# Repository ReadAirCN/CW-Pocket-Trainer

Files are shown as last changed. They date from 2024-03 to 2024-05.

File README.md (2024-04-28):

# 便携CW训练器 CW-Pocker-Trainer

## 仓库简介
  - **3D-Models**: 包含可编辑和打印的STEP模型文件。PLA文件夹内的模型建议使用PLA或其他刚性耗材打印，TPU文件夹内的模型建议使用TPU 95A或其他柔性耗材打印。
  - **Firmware**: 包含可以直接下载的固件，所有固件均可使用WCHISPTool下载， WCHISPTool的安装包也在此文件夹中，CH549G-WCHLINK-Firmware是调试芯片的固件，只需在第一次烧录即可（对于从工房买到焊好的PCB板,此固件已经烧录完成），CH32F103C8T6-Main-Firmware是主控芯片的固件，下载不同固件可以实现不同的功能，每个固件具体的介绍在该文件夹中。
  - **Keil-Project**: CW训练器的源码工程,Keil中设置调试器为CMSIS-DAP Debugger可直接编译下载到训练器。
  - 具体介绍参考项目中的 “便携CW训练器使用说明.pdf”

本项目完全开源，欢迎贡献代码。
## 交流群
QQ交流群：798617844   进群答案为：**ReadAir**



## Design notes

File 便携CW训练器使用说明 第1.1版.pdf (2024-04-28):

# 便携 CW 训练器使用说明

V1.1
BD4XUW

目录

## 1 训练器介绍

### 1.1 功能简介

便携 CW 训练器用于 QRP 爱好者在不发射的情况下进行莫斯电码的自我训练，目前支持的模式有自由 模式、训练模式、默写模式和听译模式。训练器留有一个 TypeC 接口和一个 3.5mm 音频接口，TypeC 接口 可用于串口通讯、更新固件、为训练器供电或充电（充电电流不超过 600mA）。3.5mm 音频接口可以接入耳 机，将声音输出至耳机从而在不方便外放的场合使用。

### 1.2 参数简介

⚫ | 外观尺寸：训练器主体 80*40*30mm,自动键状态 112*40*30mm;
⚫ | 电池：3.7V 800mAh 锂电池;
⚫ | 充电电流：≤600mA;
⚫ | 材质：PLA\TPU

### 1.3 拓展功能

⚫ | 更新固件
⚫ | 串口调试
⚫ | 二次开发
⚫ | 手键模式（即将添加）

## 2 使用方法

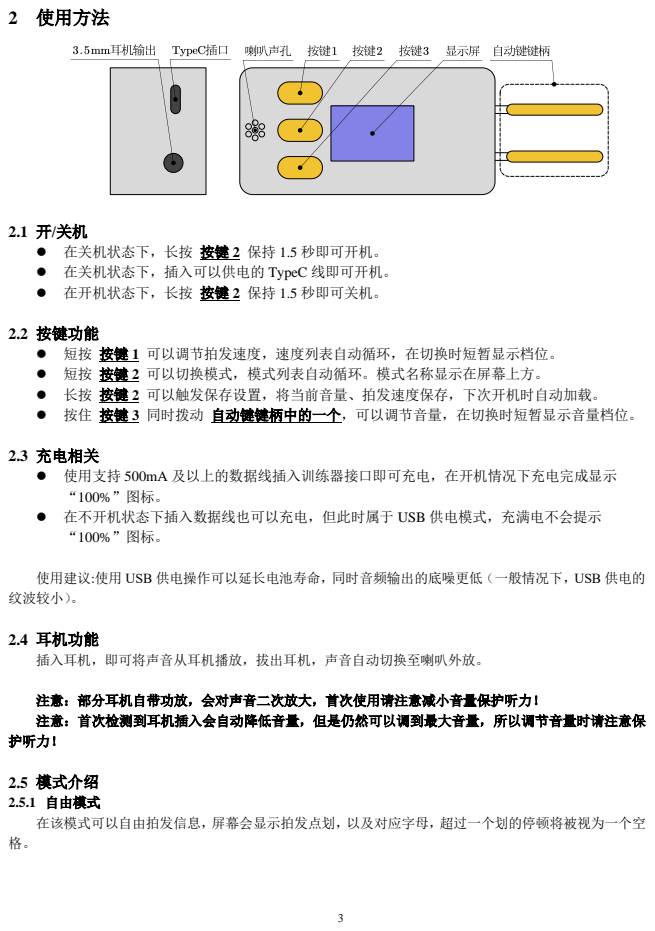
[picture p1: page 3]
在关机状态下，长按 按键 2 保持 1.5 秒即可开机。; 在关机状态下，插入可以供电的 TypeC 线即可开机。; 在开机状态下，长按 按键 2 保持 1.5 秒即可关机。; 2.2 按键功能; 短按 按键 1 可以调节拍发速度，速度列表自动循环，在切换时短暂显示档位。; 短按 按键 2 可以切换模式，模式列表自动循环。模式名称显示在屏幕上方。; 长按 按键 2 可以触发保存设置，将当前音量、拍发速度保存，下次开机时自动加载。; 按住 按键 3 同时拨动 自动键键柄中的一个，可以调节音量，在切换时短暂显示音量档位。; 2.3 充电相关; 使用支持 500mA 及以上的数据线插入训练器接口即可充电，在开机情况下充电完成显示; 在不开机状态下插入数据线也可以充电，但此时属于 USB 供电模式，充满电不会提示

使用建议:使用 USB 供电操作可以延长电池寿命，同时音频输出的底噪更低（一般情况下，USB 供电的
纹波较小）。

2.4 耳机功能
插入耳机，即可将声音从耳机播放，拔出耳机，声音自动切换至喇叭外放。

注意：部分耳机自带功放，会对声音二次放大，首次使用请注意减小音量保护听力！
注意：首次检测到耳机插入会自动降低音量，但是仍然可以调到最大音量，所以调节音量时请注意保
护听力！

2.5 模式介绍
2.5.1 自由模式
在该模式可以自由拍发信息，屏幕会显示拍发点划，以及对应字母，超过一个划的停顿将被视为一个空

2.5.2练习模式
在该模式屏幕会同时显示字母与对应点划，正确或错误拍发会播放对应提示音。准确率会显示在屏幕下 方。

2.5.3默写模式
在该模式屏幕只显示字母，操作者需要正确拍发该字母对应点划，正确或错误拍发会播放对应提示音。 准确率会显示在屏幕下方。

2.5.4听译模式
在该模式中，训练器会先播放一个字母的莫斯电码音，播放完成一次后，屏幕会会显示码元长度相等的 两个字母备选项，其中一个为正确答案，操作者拨动桨片选择正确答案。正确或错误拍发会播放对应提示 音。准确率会显示在屏幕下方。如果第一遍播放未听清，1.5 秒后会重复播放直到操作者做出选择。

### 2.6 固件更新

训练器支持更新固件和二次开发（板载调试器，支持实时调试），对于一般使用者，只需在必要时更新 固件即可。固件可在 QQ 群或 Github 工程（暂未公开）中找到。
以下是常规固件更新流程
1.在关机状态下先同时捏住双桨，此时插入带数据功能的 TypeC 线(线的一端已连接到电脑并供电)。此 时如成功，屏幕应该无显示。

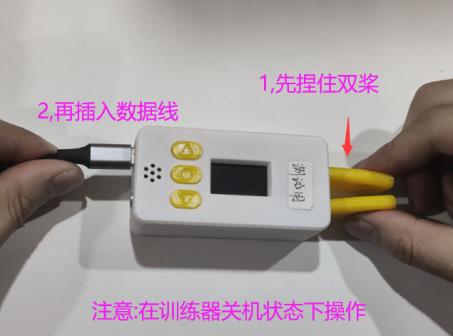
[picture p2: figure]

2.打开软件 WCHISPTOOL，选择对应 COM 口，将要下载的固件（BIN 或者 HEX 格式）放到目标程 序文件 1，确保其他选项与下图一致。

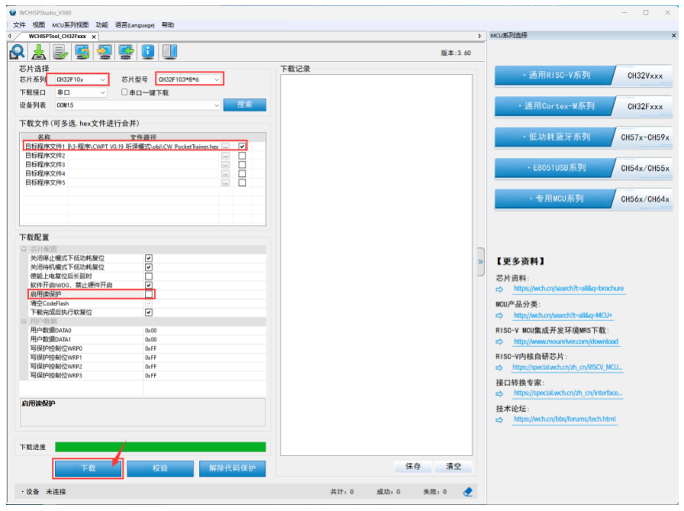
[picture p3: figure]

3.点击下载后若成功则如下图所示：

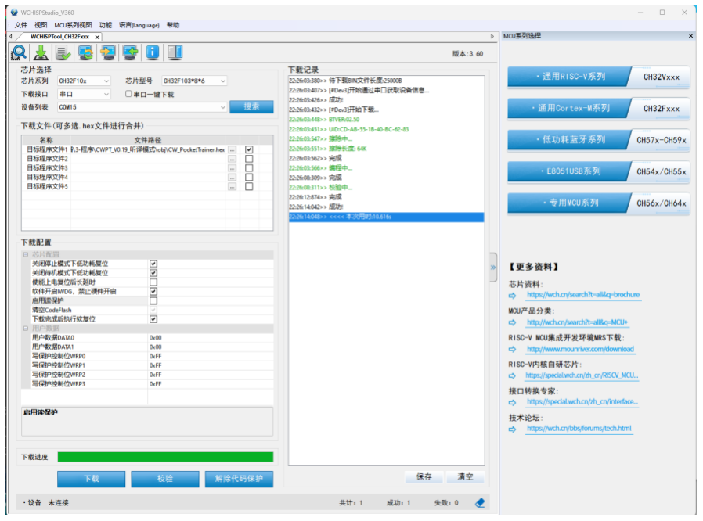
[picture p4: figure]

4.拔除数据线重新开机即可，此时已经下载好新固件了。

## 3 如何拆解

### 3.1 拆解步骤

（1）打开外壳
对于原装的训练器，如果没有粘壳，抓住键柄那一端的两侧即可打开外壳，如果粘壳了，需要 用工具（如小刀，一字螺丝刀）撬开图 1 位置，这种方法会对外壳造成破坏，不过外壳可以在 群文件或 Github 项目中下载 3D 模型自行打印。
（2）取出电池
电池使用易剥离双面胶固定，用一字螺丝刀从电池远离电路板的方向轻轻发力即可取出。 （3）取出电路板
电路板从图 3 所示缺口撬开，注意撬开后不要暴力拖拽，小心图 4 所示的喇叭线被扯断 （4）取出喇叭
喇叭使用背胶粘在外壳上，建议用镊子或其他工具小心取下，不要拉扯喇叭线以免扯断。

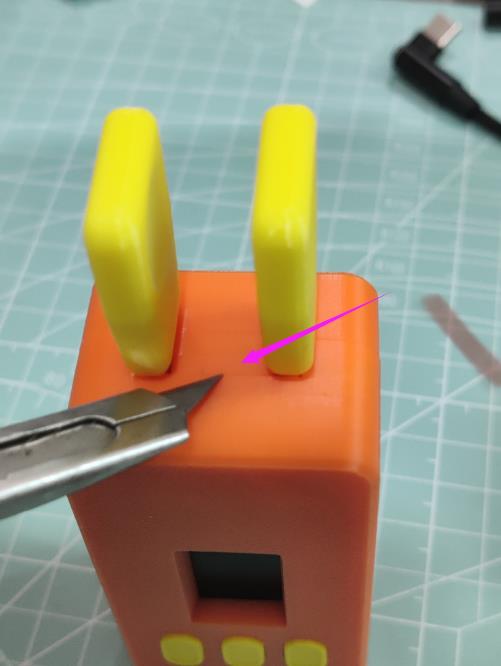
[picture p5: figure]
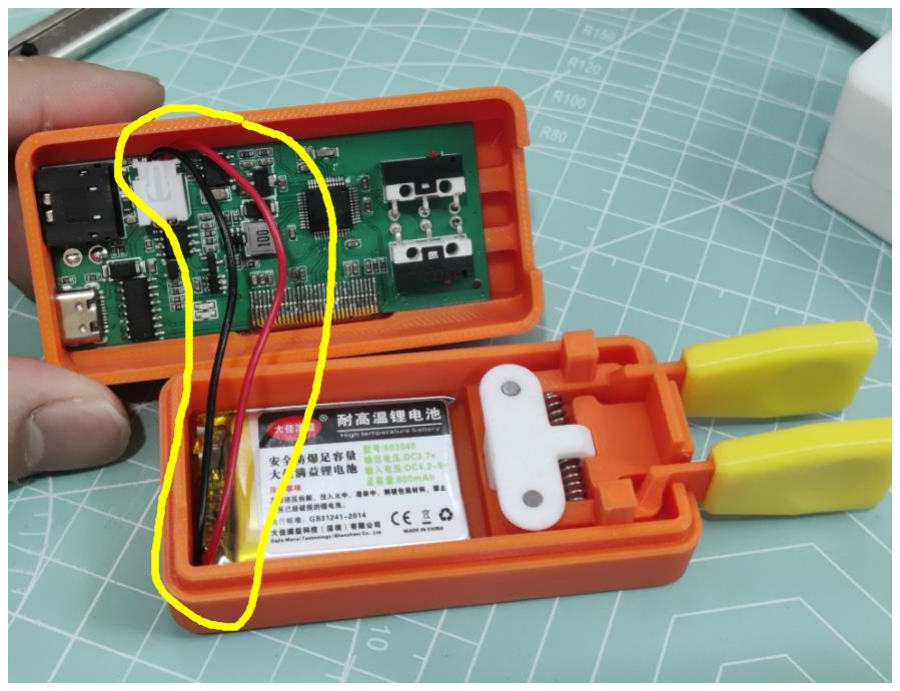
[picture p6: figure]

图 1 粘壳训练器从此处撬开 | 图 2 撬开之后小心电池线

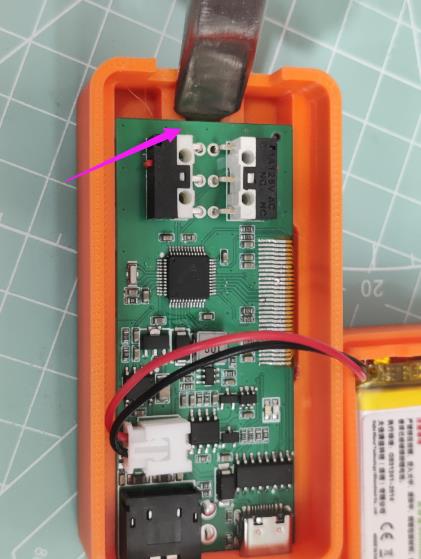
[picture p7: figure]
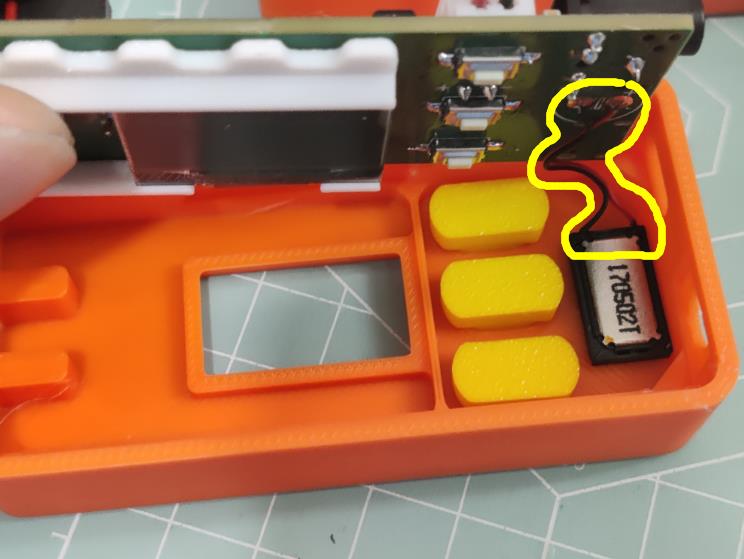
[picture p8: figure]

图 3 从图示位置可撬开电路板 | 图 4 撬开之后小心喇叭线

### 3.2 易损零件参数

名称 | 参数
锂电池 | 3.7V 聚合物锂电池 603040 800 毫安时
喇叭 | 2W 通用扬声器 16*9*2.5mm 11 号
圆柱销 | 304 不锈钢圆柱销 φ3*10
弹簧 | 304 不锈钢压簧 0.5*4*25
垫圈 | 尼龙垫圈/绝缘套管 φ3*7*5

## 4 其他

### 4.1 QQ 群

进群答案是 ReadAir

### 4.2 Bilibili 主页

https://space.bilibili.com/6397781

### 4.3 Github

正在整理代码，即将公开。

### 4.4 关于开源

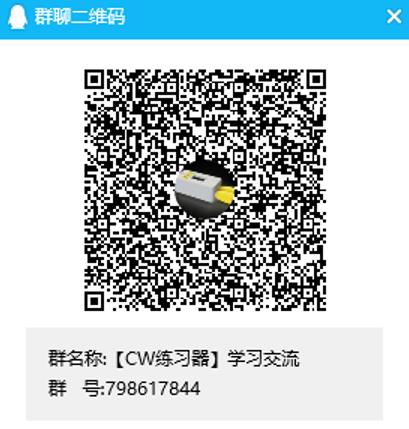
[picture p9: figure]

综合考虑后，决定开源除 PCB 生产文件之外的所有资料，开源内容包括
⚫ | 外壳三维设计文件
⚫ | 各版本固件
⚫ | 稳定版 Keil 工程
⚫ | PCB 原理图
部分内容在 Q 群中已经可以获得，

本作者对该项目的态度是：
欢迎复刻，欢迎爆改，欢迎二次创作。对于二次创作的作品，如果想售卖也没有问题，不要使用我的名 义即可。希望大家都能借助这个项目学到自己感兴趣的知识，激发大家对业余无线电以及 QRP 的兴趣。

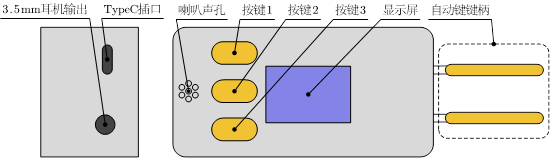
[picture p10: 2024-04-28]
image.png

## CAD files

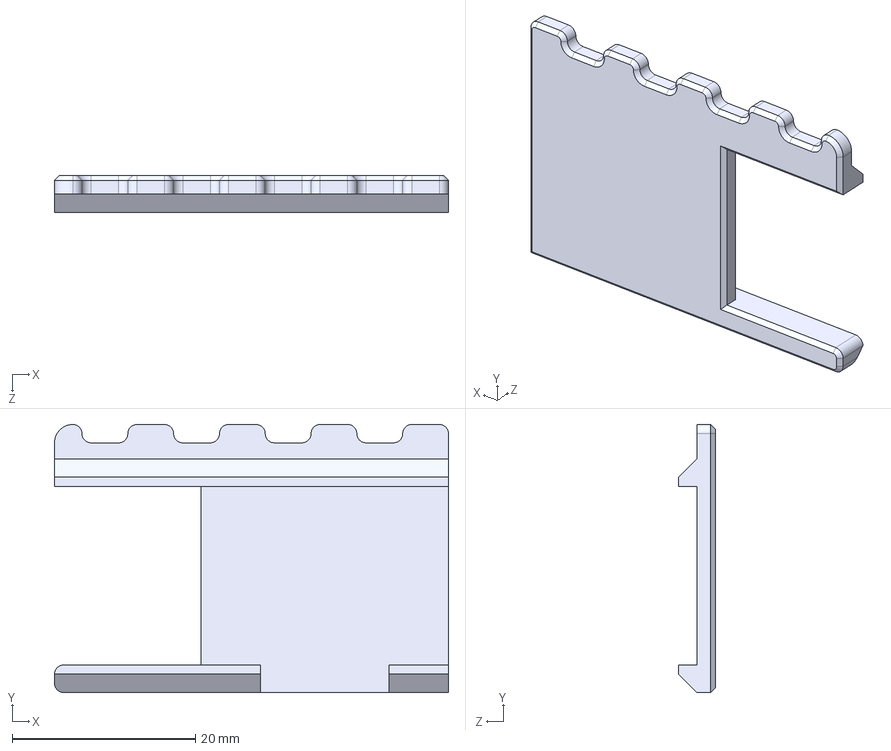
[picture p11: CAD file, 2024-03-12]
3D-Models/PLA-Material/OLED固定架.STEP
43.0 x 29.2 x 4.00 mm

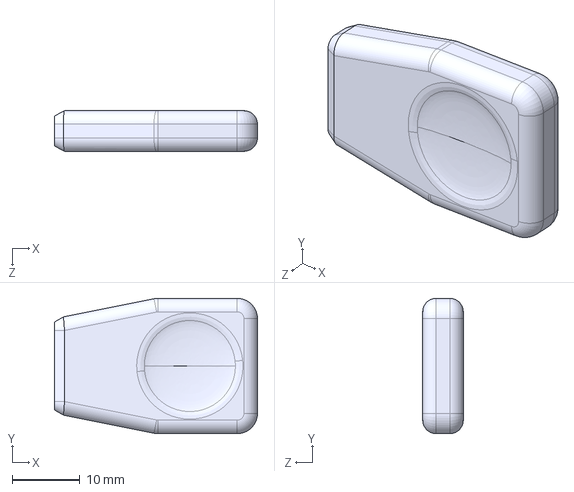
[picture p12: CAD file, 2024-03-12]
3D-Models/TPU-Material/自动键键帽.STEP
30.0 x 20.0 x 6.00 mm

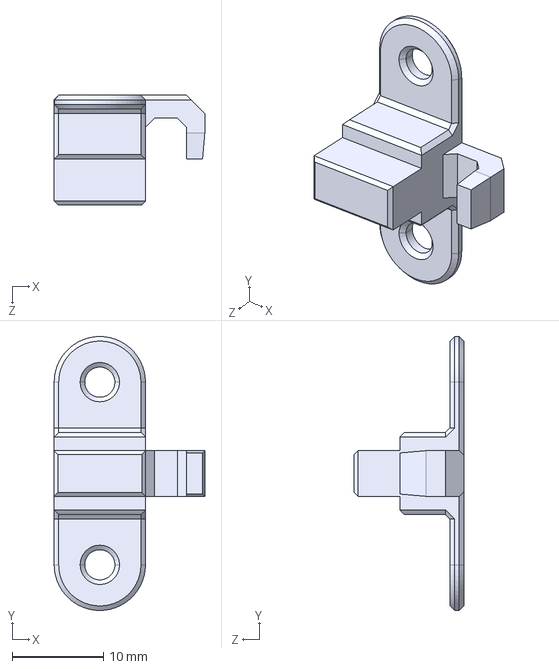
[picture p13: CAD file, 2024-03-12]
3D-Models/PLA-Material/自动键固定器.STEP
16.5 x 30.0 x 12.0 mm

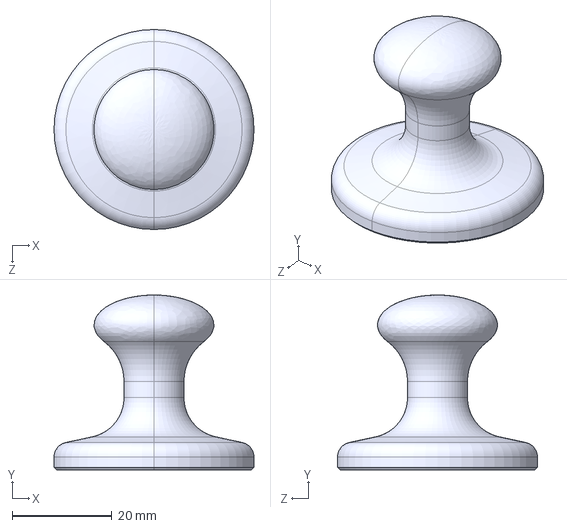
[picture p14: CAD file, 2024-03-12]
3D-Models/TPU-Material/手键键帽.STEP
40.0 x 35.0 x 40.0 mm

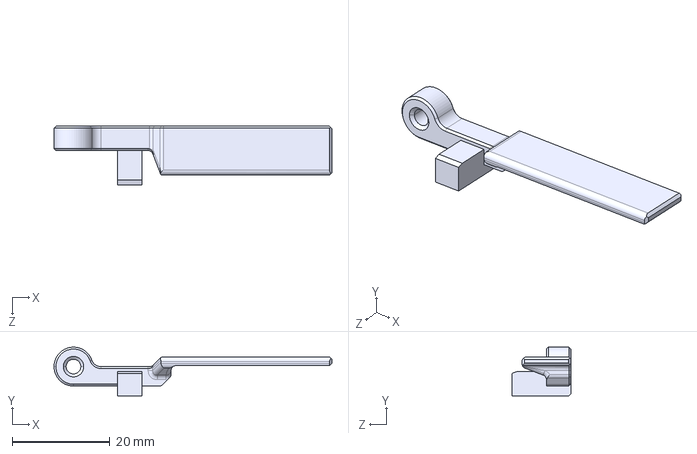
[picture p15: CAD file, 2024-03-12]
3D-Models/PLA-Material/新自动键键柄左.STEP
57.0 x 10.00 x 12.0 mm

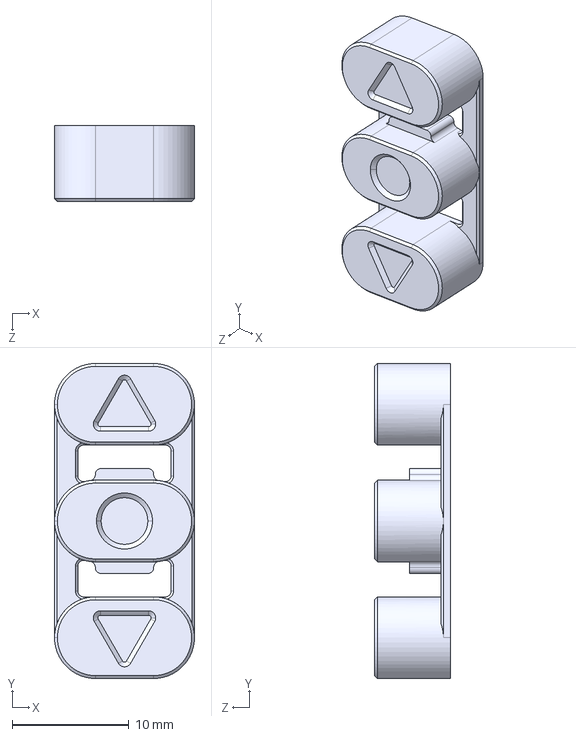
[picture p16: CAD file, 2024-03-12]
3D-Models/TPU-Material/TPU按键.STEP
12.0 x 27.0 x 6.50 mm

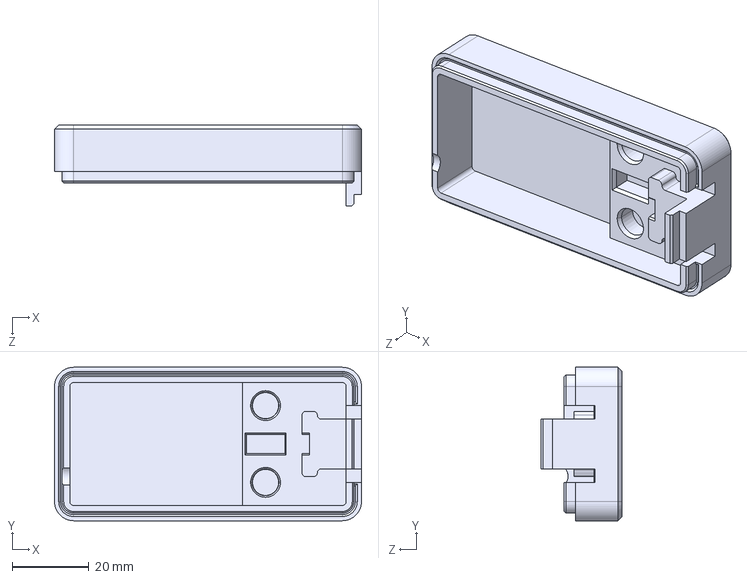
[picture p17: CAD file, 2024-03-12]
3D-Models/PLA-Material/CWPT下壳_导流槽.STEP
80.0 x 40.0 x 21.0 mm

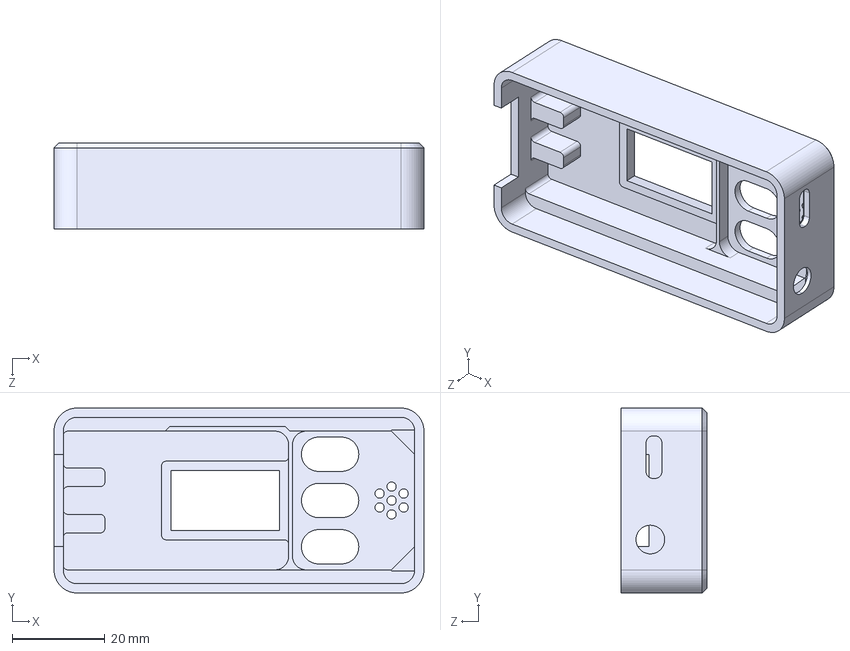
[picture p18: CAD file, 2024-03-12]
3D-Models/PLA-Material/CWPT上壳_安装导向.STEP
80.0 x 40.0 x 18.5 mm

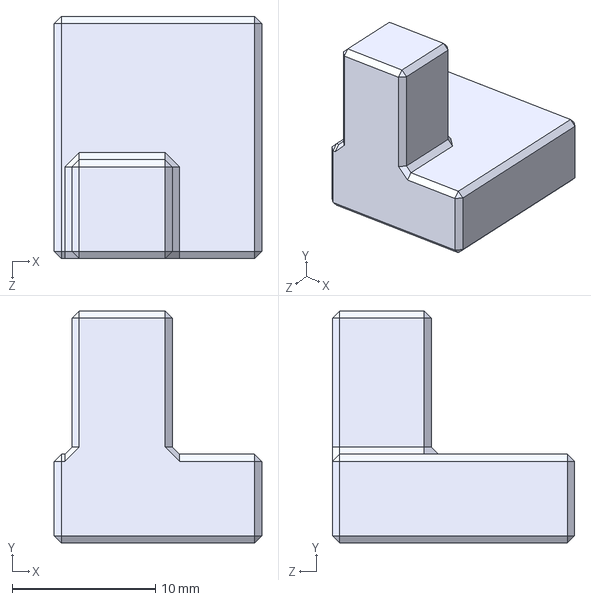
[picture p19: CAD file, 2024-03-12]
3D-Models/PLA-Material/手动键转接板.STEP
14.5 x 16.2 x 16.9 mm

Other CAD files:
3D-Models/PLA-Material/新自动键键柄右.STEP

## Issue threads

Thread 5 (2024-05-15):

关于发送队列

violarulan, 2024-05-15:
在实机操作中，使用双桨自动键可以做到发送“队列”的操作，如快速拍击“左右左”，即使手上的动作已结束，机器仍然可以输出三个交替嘀嗒。

不知可否集成这个 feature

相关链接 [S8050做的CW电路也能到2W](https://www.hellocq.net/forum/read.php?tid=170016&page=2)

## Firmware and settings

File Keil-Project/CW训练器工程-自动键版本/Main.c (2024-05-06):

#include "debug.h"
// 显示屏驱动
#include "oled.h" 
// ADC驱动，包括电池电压和耳机插入检测
#include "BSP_adc.h"
// 按键和自动键初始化
#include "Key.h"
// 电池与TP4056初始化
#include "battery.h"
// 喇叭功放驱动
#include "beep.h"
// 定时器驱动，包括主程序逻辑
#include "timer.h"
// FLASH保存
#include "flash.h"
// DAC驱动，包括喇叭发生驱动
#include "dac.h"
// OLED用户交互函数
#include "oled_ui.h"
// 莫斯电码相关
#include "cw.h"
// 标准库函数
#include <stdlib.h>



// 音量幅值列表
const float VolumeList[9]={0.0003,0.001,0.003,0.1,0.2,0.4,0.6,0.8,1};
// 音量改动标志位
u8 VolumeChange_Flag = 0;
// 音量修改标志位
u8 VolumeModified_Flag = 1;
// 耳机模式标志位
u8 EarPhone_MODE_FLAG = 0;
void HardWare_Init(void)
{
		// 延迟函数初始化
		Delay_Init();
		// 设置系统中断优先级分组
		NVIC_PriorityGroupConfig(NVIC_PriorityGroup_2); 
		/* 串口调试初始化（发行版暂时不需要）*/
		/* USART_Printf_Init(115200); */ 
		// OLED初始化
		OLED_Init();
		// 电池电压ADC初始化
		BSP_ADC_Init();
		// 按键初始化
		Button_Init();
		// 电键初始化
		DKEY_Init();
		// 充电芯片状态识别初始化
		Battery_TP4056_GPIO_Init();
		// 功放静音输出初始化
		AmpSD_GPIO_Init();
		// 创建MorseTree
		MorseTree_Init();
		// 定时器初始化(1000Hz)
		TIM1_TASK_Init(1000-1,72-1);
		delay_ms(10);
		// Flash读写初始化
		
		// DAC初始化
		DAC_MUSIC_Init();
		// 正弦波波以及调整音量
		EarPhone_WAVE(WAV_DATA3,VolumeList[VolumeList_index]);
		VolumeModified_Flag = 1;
		// 初始化随机数生成器
    srand((unsigned int)Battery_Voltage+TIM1->CNT);
}


int main( void )
{
	u8 key_value=0;
	
	//初始化
	HardWare_Init();

	OLED_Refresh_Gram();
	BSP_Flash_Read_Info();
	
	{/*更新时间设定*/
	switch(GLOBAL_SendSpeed)
	{
		case SendSpeed_Slow:
		{
			time_dit = TIME_SLOW_dit;
			break;     
		}              
		case SendSpeed_Middle:
		{
			time_dit = TIME_MIDD_dit;
			break;
		}	
		case SendSpeed_High:
		{
			time_dit = TIME_HIGH_dit;
			break;
		}
		case SendSpeed_Super:
		{
			time_dit = TIME_SUPR_dit;
			break;
		}	
	}
	time_dah = 3 * time_dit;
	time_space_bit = time_dit;
	time_space_letter = 3 * time_dit;
	time_space_word = 7 * time_dit;
	}/*更新时间设定*/
	
//BSP_Flash_Write_Info();
	
	{ // 修复开机爆破音
		EarPhone_WAVE(WAV_DATA3,VolumeList[VolumeList_index]);
		DAC_SetFreq(1000);
		TIM_Cmd(TIM3, ENABLE);
		AMP_SD = 0;
	} // 修复开机爆破音
	while(1)
	{
		// 按键检测
		key_value = Button_Scan();
		// 强制打乱，可能没有意义
		srand((unsigned int)Battery_Voltage+TIM1->CNT);
		
		if (key_value == BUTTON_DEC_PRES)//切换拍发速度
		{
			switch(GLOBAL_SendSpeed)
			{
				case SendSpeed_Slow:
				{
					GLOBAL_SendSpeed = SendSpeed_Middle;
					time_dit = TIME_MIDD_dit;
					break;     
				}              
				case SendSpeed_Middle:
				{
					GLOBAL_SendSpeed = SendSpeed_High;
					time_dit = TIME_HIGH_dit;
					break;
				}	
				case SendSpeed_High:
				{
					GLOBAL_SendSpeed = SendSpeed_Super;
					time_dit = TIME_SUPR_dit;
					break;
				}
				case SendSpeed_Super:
				{
					GLOBAL_SendSpeed = SendSpeed_Slow;
					time_dit = TIME_SLOW_dit;
					break;
				}	
			}	
			// 更新时间设定
			time_dah = 3 * time_dit;
			time_space_bit = time_dit;
			time_space_letter = 3 * time_dit;
			time_space_word = 7 * time_dit;
			UI_SendSpeedDisplay(GLOBAL_SendSpeed);
			OLED_Refresh_Gram();
			delay_ms(500);
		}
		else if (key_value == BUTTON_MODE_PRES) // 切换模式（自由练习，看字直发，看字盲发，听译模式）
		{
			OLED_Clear();
			// 目的是防止上一个模式中的音乐没有放完
			TIM_Cmd(TIM3, DISABLE);
			// 目的是确保进入新模式的时候新生成一个字母
			GLOBAL_FLAG_NewLetter = 1;
			// 设置初始准确率，只是为了好看
			GLOBAL_ratio_correct = 100.0;
			switch(GLOBAL_WorkMode)
			{
				case WorkMode_FreeType:
				{
					GLOBAL_WorkMode = WorkMode_RandType;
					break;     
				}              
				case WorkMode_RandType:
				{
					GLOBAL_WorkMode = WorkMode_BlindType;
					break;
				}	
				case WorkMode_BlindType:
				{
					GLOBAL_WorkMode = WorkMode_ListenType;
					break;
				}	
				case WorkMode_ListenType:
				{
					GLOBAL_WorkMode = WorkMode_FreeType;
					strcpy(GLOBAL_BottomString,"                ");
					ClearStr(CW_Code,7);
					CW_Letter='\0';
					break;
				}	
			}	
		}
		// 按住第三按键
		if (BUTTON_INC == 0)
		{
			// 编辑音量时不响应CW逻辑
			GLOBAL_FLAG_WORKING = 0;
			
			if ((DKEY_A == 1) && (DKEY_B == 1))//松开视为已经修改
			{
				VolumeChange_Flag = 0;
				if (VolumeModified_Flag == 0)
				{
					// 调整音量
					EarPhone_WAVE(WAV_DATA3,VolumeList[VolumeList_index]);
					VolumeModified_Flag = 1;
					UI_VolumeDisplay(VolumeList_index);
					OLED_Refresh_Gram();
					TIM_Cmd(TIM3, ENABLE);
					delay_ms(300);
					TIM_Cmd(TIM3, DISABLE);
				}
			}
			if (VolumeChange_Flag == 0)
			{
				if (DKEY_A == 0)//音量+
				{
					VolumeList_index = (VolumeList_index >= 8)?8:VolumeList_index +1;
					VolumeChange_Flag = 1;
					VolumeModified_Flag = 0;
				}
				else	if (DKEY_B == 0)//音量-
				{
					VolumeList_index = (VolumeList_index == 0)?0:VolumeList_index -1;
					VolumeChange_Flag = 1;
					VolumeModified_Flag = 0;
				}
			}
		}
		else
		{
			GLOBAL_FLAG_WORKING = 1;
		}
		

		if (GLOBAL_WorkMode==WorkMode_FreeType) //自由模式
		{
			UI_MorceCode();
		}
		else if (GLOBAL_WorkMode==WorkMode_RandType)//练习模式
		{
			// 绘制字母和滴答
			OLED_ShowChar_2216(0,22,GLOBAL_CorrectLetter);
			// 绘制点划
			UI_DrawDitDah((char *)MorseDictionary[letter2num(GLOBAL_CorrectLetter)]);
			// 显示准确率
			OLED_ShowCH_16(0,48,8);
			OLED_ShowCH_16(16,48,9);
			OLED_ShowCH_16(32,48,10);
			OLED_ShowString(48,48,":      ",16);
			OLED_Show3FNum(60,48,GLOBAL_ratio_correct,3,2,16);
			OLED_ShowString(116,48,"%",16);
		}
		else if (GLOBAL_WorkMode==WorkMode_BlindType)//默写模式
		{
			// 绘制字母和滴答
			OLED_ShowChar_2216(0,22,GLOBAL_CorrectLetter);
			// 绘制点划
			if(GLOBAL_incorrect_counter >= TIPS_THD)
			{
				UI_DrawDitDah((char *)MorseDictionary[letter2num(GLOBAL_CorrectLetter)]);
			}
			else
			{
				UI_DrawDitDah((char *)CW_Code);
			}
			// 显示准确率
			OLED_ShowCH_16(0,48,8);
			OLED_ShowCH_16(16,48,9);
			OLED_ShowCH_16(32,48,10);
			OLED_ShowString(48,48,":      ",16);
			OLED_Show3FNum(60,48,GLOBAL_ratio_correct,3,2,16);
			OLED_ShowString(116,48,"%",16);
		}
		else if (GLOBAL_WorkMode==WorkMode_ListenType)//听译模式
		{
			// 绘制点划
			//UI_DrawDitDah((char *)CW_Code);
			// 显示准确率
			OLED_ShowCH_16(0,32,8);
			OLED_ShowCH_16(16,32,9);
			OLED_ShowCH_16(32,32,10);
			OLED_ShowString(48,32,":",16);
			OLED_ShowString(0,48,"       %     ",16);
			OLED_Show3FNum(0,48,GLOBAL_ratio_correct,3,2,16);
			// 绘制字母和滴答
			OLED_ShowChar_2216(100,18,GLOBAL_ChoiceA);
			OLED_ShowChar_2216(100,42,GLOBAL_ChoiceB);
		}
		// 绘制电池电量	
		UI_DrawBattery();
		// 绘制模式描述
		UI_ShowMode();
		// 耳机检测
		UI_EarPhoneCheck();
		// 自动保存检测
		UI_AutoSaveSetting();
		//耳机音量自动调低 仅首次进入执行
		if ((EarphoneEnd_Voltage > 4050)&&(EarPhone_MODE_FLAG == 0))
		{
			EarPhone_MODE_FLAG = 1;
			VolumeList_index = (VolumeList_index>2) ? 2 : VolumeList_index;
			EarPhone_WAVE(WAV_DATA3,VolumeList[VolumeList_index]);
			UI_VolumeDisplay(VolumeList_index);
			OLED_Refresh_Gram();
			delay_ms(250);
			VolumeModified_Flag = 0;
		}
		else if (EarphoneEnd_Voltage < 4000)
		{
			EarPhone_MODE_FLAG = 0;
		}
		// 更新显存
		OLED_Refresh_Gram();
	}
}

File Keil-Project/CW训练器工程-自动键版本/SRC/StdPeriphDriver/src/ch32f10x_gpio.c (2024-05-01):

/********************************** (C) COPYRIGHT  *******************************
 * File Name          : ch32f10x_gpio.c
 * Author             : WCH
 * Version            : V1.0.0
 * Date               : 2019/10/15
 * Description        : This file provides all the GPIO firmware functions.
 *********************************************************************************
* Copyright (c) 2021 Nanjing Qinheng Microelectronics Co., Ltd.
* Attention: This software (modified or not) and binary are used for 
* microcontroller manufactured by Nanjing Qinheng Microelectronics.
*******************************************************************************/
#include "ch32f10x_gpio.h"
#include "ch32f10x_rcc.h"


/* RCC registers bit address in the alias region */
#define AFIO_OFFSET                  (AFIO_BASE - PERIPH_BASE)

/* ECR Register */
/* Alias word address of EVOE bit */
#define ECR_OFFSET                   (AFIO_OFFSET + 0x00)
#define EVOE_BitNumber               ((uint8_t)0x07)
#define ECR_EVOE_BB                  (PERIPH_BB_BASE + (ECR_OFFSET * 32) + (EVOE_BitNumber * 4))


/* PCFR1 Register */
/* Alias word address of MII_RMII_SEL bit */
#define PCFR1_OFFSET                 (AFIO_OFFSET + 0x04)
#define MII_RMII_SEL_BitNumber       ((u8)0x17)
#define PCFR1_MII_RMII_SEL_BB        (PERIPH_BB_BASE + (PCFR1_OFFSET * 32) + (MII_RMII_SEL_BitNumber * 4))

#define ECR_PORTPINCONFIG_MASK      ((uint16_t)0xFF80)
#define LSB_MASK                    ((uint16_t)0xFFFF)
#define DBGAFR_POSITION_MASK        ((uint32_t)0x000F0000)
#define DBGAFR_SWJCFG_MASK          ((uint32_t)0xF0FFFFFF)
#define DBGAFR_LOCATION_MASK        ((uint32_t)0x00200000)
#define DBGAFR_NUMBITS_MASK         ((uint32_t)0x00100000)


/*********************************************************************
 * @fn      GPIO_DeInit
 *
 * @brief   Deinitializes the GPIOx peripheral registers to their default
 *        reset values.
 *
 * @param   GPIOx - where x can be (A..G) to select the GPIO peripheral.
 *
 * @return  none
 */
void GPIO_DeInit( GPIO_TypeDef *GPIOx )
{
    if( GPIOx == GPIOA )
    {
        RCC_APB2PeriphResetCmd( RCC_APB2Periph_GPIOA, ENABLE );
        RCC_APB2PeriphResetCmd( RCC_APB2Periph_GPIOA, DISABLE );
    }
    else if( GPIOx == GPIOB )
    {
        RCC_APB2PeriphResetCmd( RCC_APB2Periph_GPIOB, ENABLE );
        RCC_APB2PeriphResetCmd( RCC_APB2Periph_GPIOB, DISABLE );
    }
    else if( GPIOx == GPIOC )
    {
        RCC_APB2PeriphResetCmd( RCC_APB2Periph_GPIOC, ENABLE );
        RCC_APB2PeriphResetCmd( RCC_APB2Periph_GPIOC, DISABLE );
    }
    else if( GPIOx == GPIOD )
    {
        RCC_APB2PeriphResetCmd( RCC_APB2Periph_GPIOD, ENABLE );
        RCC_APB2PeriphResetCmd( RCC_APB2Periph_GPIOD, DISABLE );
    }
    else if( GPIOx == GPIOE )
    {
        RCC_APB2PeriphResetCmd( RCC_APB2Periph_GPIOE, ENABLE );
        RCC_APB2PeriphResetCmd( RCC_APB2Periph_GPIOE, DISABLE );
    }
    else if( GPIOx == GPIOF )
    {
        RCC_APB2PeriphResetCmd( RCC_APB2Periph_GPIOF, ENABLE );
        RCC_APB2PeriphResetCmd( RCC_APB2Periph_GPIOF, DISABLE );
    }
    else
    {
        if( GPIOx == GPIOG )
        {
            RCC_APB2PeriphResetCmd( RCC_APB2Periph_GPIOG, ENABLE );
            RCC_APB2PeriphResetCmd( RCC_APB2Periph_GPIOG, DISABLE );
        }
    }
}

/*********************************************************************
 * @fn      GPIO_AFIODeInit
 *
 * @brief   Deinitializes the Alternate Functions (remap, event control
 *        and EXTI configuration) registers to their default reset values.
 *
 * @return  none
 */
void GPIO_AFIODeInit( void )
{
    RCC_APB2PeriphResetCmd( RCC_APB2Periph_AFIO, ENABLE );
    RCC_APB2PeriphResetCmd( RCC_APB2Periph_AFIO, DISABLE );
}
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

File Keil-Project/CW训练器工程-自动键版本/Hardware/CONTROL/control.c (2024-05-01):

#include "control.h"

u16 ADC_HALL_X_OFFSET=2048;
u16 ADC_HALL_Y_OFFSET=2048;
u16 ADC_HALL_Z_OFFSET=2048;

void TIM1_UP_IRQHandler(void)
{

		if(TIM_GetITStatus(TIM1, TIM_IT_Update) == SET)//判断1ms定时标志位是否置1
    {
      //中断处理代码//////////////////////////////////////
			//LED = ~LED;
			//Control_BangBang();
			Control_PID();
			////////////////////////////////////////////////////
       TIM_ClearITPendingBit(TIM1, TIM_IT_Update);//清除中断标志位
    }
} 

void TIM1_Init(u16 arr, u16 psc)
{
    TIM_TimeBaseInitTypeDef TIM_TimeBaseInitStructure = {0};
    NVIC_InitTypeDef NVIC_InitStruct;
    RCC_APB2PeriphClockCmd(RCC_APB2Periph_TIM1, ENABLE);

    TIM_TimeBaseInitStructure.TIM_Period = arr;
    TIM_TimeBaseInitStructure.TIM_Prescaler = psc;
    TIM_TimeBaseInitStructure.TIM_ClockDivision = TIM_CKD_DIV1;
    TIM_TimeBaseInitStructure.TIM_CounterMode = TIM_CounterMode_Up;
    TIM_TimeBaseInit(TIM1, &TIM_TimeBaseInitStructure);

    TIM_ITConfig(TIM1, TIM_IT_Update, ENABLE);
    TIM_ClearITPendingBit(TIM1, TIM_IT_Update);
    NVIC_InitStruct.NVIC_IRQChannel = TIM1_UP_IRQn;
    NVIC_InitStruct.NVIC_IRQChannelPreemptionPriority = 1;
    NVIC_InitStruct.NVIC_IRQChannelSubPriority = 2;
    NVIC_InitStruct.NVIC_IRQChannelCmd = ENABLE;
    NVIC_Init(&NVIC_InitStruct);

    TIM_Cmd(TIM1, ENABLE);
		
} 

void Control_Init(void)
{
	TIM1_Init(1000-1,72-1); // 1000Hz
}

u8 sign_int(int num)
{
	return (num>0)?1:((num==0)?0:-1);
}

void Control_BangBang(void)
{
	int dead_zone = 0;
	int hall_x_center = 1990;
	int hall_y_center = 2032;
	int normal_duty = 100;
	
	if (ADC_HALL_X > hall_x_center+dead_zone)
	{
		SetCoilVoltageDuty(Coil_A,normal_duty);
		SetCoilVoltageDuty(Coil_C,-normal_duty);
	}
	else if (ADC_HALL_X < hall_x_center-dead_zone)
	{
		SetCoilVoltageDuty(Coil_A,-normal_duty);
		SetCoilVoltageDuty(Coil_C,+normal_duty);
	}
	
		if (ADC_HALL_Y > hall_x_center+dead_zone)
	{
		SetCoilVoltageDuty(Coil_B,normal_duty);
		SetCoilVoltageDuty(Coil_D,-normal_duty);
	}
	else if (ADC_HALL_Y < hall_x_center-dead_zone)
	{
		SetCoilVoltageDuty(Coil_B,-normal_duty);
		SetCoilVoltageDuty(Coil_D,+normal_duty);
	}
		
}	

void Control_PID(void)
{
		int dead_zone = 0;
	int hall_x_center = 2020;
	int hall_y_center = 2020;
	int normal_duty = 100;
	
	static idx = 0;
	static float Dif_Hall_x_fifo[8]={0};
	static float Dif_Hall_y_fifo[8]={0};
	static float Lst_Hall_x,Lst_Hall_y;
	static float sum_Diff_Hall_x=0;
	static float sum_Diff_Hall_y=0;
	
	
	
	float Now_Hall_x,Now_Hall_y;
	float Exp_Hall_x,Exp_Hall_y;
	float Err_Hall_x,Err_Hall_y;
	float Dif_Hall_x,Dif_Hall_y;
	float Out_Duty_x,Out_Duty_y;
	float K_p=1.6f;
	float K_d=15.0f;

	
	Exp_Hall_x = 0;
	Exp_Hall_y = 0;
	
	Dif_Hall_x = 0;
	Dif_Hall_y = 0;
	
	Now_Hall_x = ADC_HALL_X - ADC_HALL_X_OFFSET;
	Now_Hall_y = ADC_HALL_Y - ADC_HALL_Y_OFFSET;
	
	sum_Diff_Hall_x -= Dif_Hall_x_fifo[idx];
	sum_Diff_Hall_y -= Dif_Hall_y_fifo[idx];
	
	Dif_Hall_x_fifo[idx] = Now_Hall_x - Lst_Hall_x;
	Dif_Hall_y_fifo[idx] = Now_Hall_y - Lst_Hall_y;
	
	sum_Diff_Hall_x += Dif_Hall_x_fifo[idx];
	sum_Diff_Hall_y += Dif_Hall_y_fifo[idx];
	
	Lst_Hall_x = Now_Hall_x;
	Lst_Hall_y = Now_Hall_y;
	
	Dif_Hall_x = sum_Diff_Hall_x/8.0f;
	Dif_Hall_y = sum_Diff_Hall_y/8.0f;
	
	idx = (idx==(8-1))?0:idx+1;
	
	Err_Hall_x = Exp_Hall_x - Now_Hall_x;
	Err_Hall_y = Exp_Hall_y - Now_Hall_y;
	
	Out_Duty_x = K_p * Err_Hall_x + K_d * (-Dif_Hall_x);
	Out_Duty_y = K_p * Err_Hall_y + K_d * (-Dif_Hall_y);

	
	SetCoilVoltageDuty(Coil_A,(int)(-Out_Duty_x));
	SetCoilVoltageDuty(Coil_C,(int)(Out_Duty_x));
														
	SetCoilVoltageDuty(Coil_B,(int)(-Out_Duty_y));
	SetCoilVoltageDuty(Coil_D,(int)(Out_Duty_y));
	
	if (ADC_HALL_H<1500) EnableCoilOutput();
	else DisableCoilOutput();
}	

void Control_SMC(void)
{
	
}	

// 运行此函数更新中位时刻的XY的霍尔值
void GetHallCenter(void)
{
	u8 num=16;//n次平均值
	u8 i;
	u32 sum_hall_x=0; 
	u32 sum_hall_y=0; 
	for(i=0;i<num;i++)
	{
		sum_hall_x += ADC_HALL_X;
		sum_hall_y += ADC_HALL_Y;
	}
	ADC_HALL_X_OFFSET = sum_hall_x/num;
	ADC_HALL_Y_OFFSET = sum_hall_y/num;
}

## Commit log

2024-03-12 添加模型
    [CWPT上壳_安装导向.STEP, CWPT下壳_导流槽.STEP, OLED固定架.STEP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]
2024-03-12 First upload
    [CWPT上壳_安装导向.STEP, CWPT下壳_导流槽.STEP, OLED固定架.STEP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]
2024-04-28 增加keil工程，增加手册
2024-04-28 提交源码工程
2024-04-28 修改工程名
2024-04-28 添加鸡音盒固件
2024-05-06 增加随机默写模式下的错误提示
